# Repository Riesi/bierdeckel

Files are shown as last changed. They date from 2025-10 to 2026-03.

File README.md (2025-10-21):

# Introduction
This is the implementation of an open hardware smart beer coaster.
As a core principle the beer coaster is simply a battery powered scale with LEDs and BLE.
These components enable a variety of interesting applications that can be implemented on top of the provided hardware.
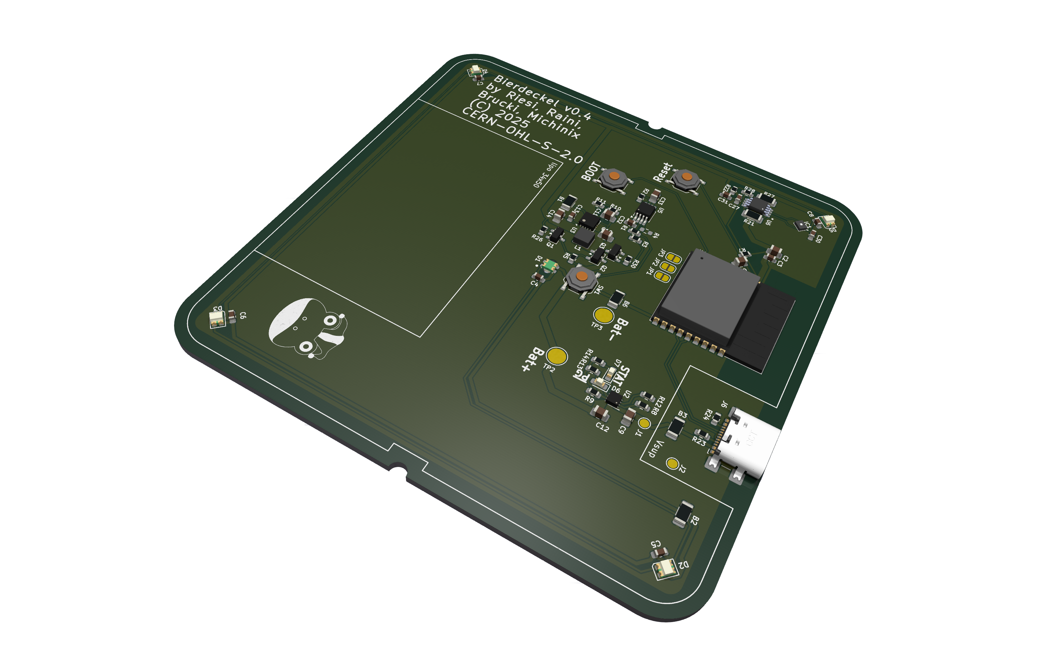
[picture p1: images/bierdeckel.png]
Beerc coaster PCB


## Default app
Currently the default app implementation is a hardcoded rainbow pattern, which gets dimmed relative to the analog input value of the force sensor's measurement. Due to part to part variance on the assembled PCBs the analog values can be different, which means the internal thresholds have to be adapted between PCBs.

## Electro-Mechanical Core Principle
The core component to allow for weight measurements is the piezo-electric force sensor. This sensor translates the force transferred from the coaster's feet into an electric signal, which can be used by the ESP32-C3 microcontroller.

# Code
The code is written in Rust and built with the Rust toolchain provided by Espressif. **It is highly recommended to use Linux for building the code**. The Windows version of the tools needed have some issues, which will make it a lot harder or almost impossible to build the project.

## Setup
There are a few things to install to properly build and flash the firmware onto the device. 
First and foremost the general Rust tooling has to be installed. This means installing `rustup` and making sure `cargo` is working.

### Quickstart on Arch
On Arch you can simply install `rustup`, `espup` and `espflash` via the package manager. You still need to run the toolchain downloads/installs, but you dont have to build anything.
```
sudo pacman -S base-devel rustup espup espflash
rustup default stable
espup install
```
### ESP Toolchain
For the ESP toolchain one has to follow the installation and quickstart guide on the `espup` repository.

https://github.com/esp-rs/espup?tab=readme-ov-file#installation

### Flash Tool
To flash the built firmware the `espflash` tool is needed:

https://github.com/esp-rs/espflash/blob/main/cargo-espflash/README.md#installation

## Building
If everything got properly installed and configured in the previous steps, to build the code one has to simply call:

```
cargo build
```

## Flashing
To build and flash the firmware onto the microcontroller the following command is needed:

```
cargo espflash flash -B 115200 --partition-table partitions.csv --erase-parts ota_1
```

### OTA
The reference beer coaster code implements an OTA update scheme with A/B partitioning.
To generate a OTA-image you simply have to run:

```
espflash save-image --chip esp32c3 target/riscv32imc-esp-espidf/debug/beercoaster beercoaster.bin
```

After this you have to copy the `beercoaster.bin` file into the `bt_flasher` folder and run the flasher with:
```
cargo run
```

## Serial
To connect to the serial interface of the beer coaster this command can be used:
```
espflash  monitor -p /dev/ttyUSB0 -B 115200
```

# PCB Design
The PCB is designed with KiCad. The project should contain all the components to work with it.
When ordering the current version a 1.6mm thick single layer PCB is required, due to assumptions from the mechanical base plate.

# Mechanical
This part of the project is done in FreeCAD and consists of 2 parts which act as the housing for the PCB. The mechanical parts are designed to be 3d printable. The base clips onto the PCB and holds itself in place. 
The key feature of the mechanical design are thin membrane sections, which allow these sections of the base plate to elastically deform. This enables the actuation of buttons on the PCB and the pressure sensor for the weight measurement.

## Material
The design has been tested with PET and ASA, but you can use anything that is:
* water resistant
* doesn't degrade under cyclical deformation
* allows for enough flex to actuate buttons and the pressure sensor

## Assembly Water Tightness
* It is recommended to use silicone to seal the sides of the assembly from water ingress.
* The center LED has to be covered with clear resin to prevent water from getting in.

## BoM
| Part | Amount |
| ---  | --- |
| Base | 1 |
| Foot | 4 |

# Calculations
Contains some files with related calculations for the PCB design. 

# Licensing
The different parts of the beer coaster require different licenses, due to the licenses only covering for example either code or hardware. For this reason the repository contains different licenses. Each subfolder contains the appropriate license for all files and subfolders within.
The current licenses used are:
* GPL-3.0
* CERN-OHL-S-2.0
* Beerware

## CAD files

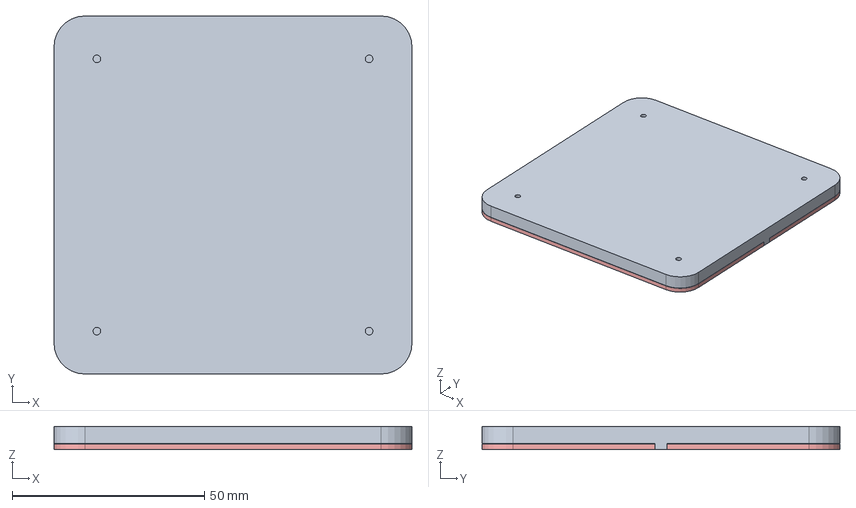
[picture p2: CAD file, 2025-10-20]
mechanical/bierdeckel_base.FCStd
93.0 x 93.0 x 6.10 mm
LED_RGB_1210
C_0805_2012Metric
SOT-23-3
SW_SPST_TL3342
C_0603_1608Metric
R_0603_1608Metric
C_0603_1608Metric020
R_0603_1608Metric034
R_0603_1608Metric035
LED_0603_1608Metric
SW_SPST_TL3348
R_1206_3216Metric
LED_RGB_1220
LED_RGB_1221
ESP32-C3-WROOM-02
C_0805_2012Metric016
R_0603_1608Metric036
R_0603_1608Metric037
C_0805_2012Metric017
C_0603_1608Metric021
USB4110-GF-A001
USB4110-GF-A002
C_0805_2012Metric018
SW_SPST_TL3349
C_0805_2012Metric019
C_0603_1608Metric022
R_0603_1608Metric038
R_1206_3216Metric012
R_0603_1608Metric039
R_0603_1608Metric040
C_0805_2012Metric020
R_0603_1608Metric041
C_0603_1608Metric023
R_0603_1608Metric042
WSON-8-1EP_2x2mm_P0.5mm_EP0.9x1.6mm
C_0603_1608Metric024
R_0603_1608Metric043
R_1206_3216Metric013
R_1206_3216Metric014
SOT-23
R_0603_1608Metric044
LED_RGB_1222
Force_sensor_Knob_ÃÂÃÂ³400um_without mark001
Force_sensor_Knob_ÃÂÃÂ³400um_without mark002
SOT-024
R_0603_1608Metric045
C_0805_2012Metric021
C_0603_1608Metric025
R_0603_1608Metric046
C_0603_1608Metric026
R_0603_1608Metric047
R_0603_1608Metric048
R_0603_1608Metric049
C_0603_1608Metric027
R_1206_3216Metric015
R_0603_1608Metric050
R_1206_3216Metric016
LED_0603_1608Metric004
VSSOP-8_3x3mm_P0.65mm
LED_RGB_1223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

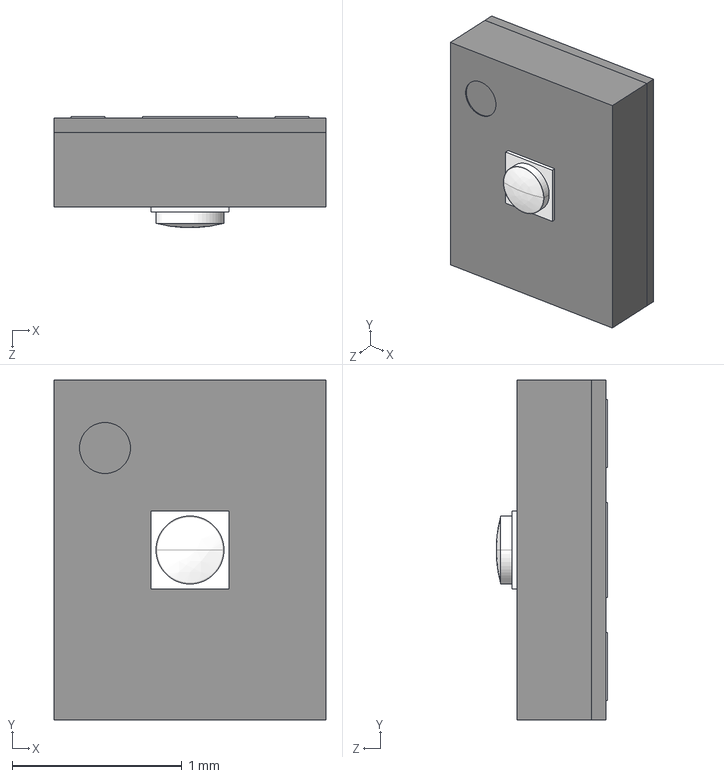
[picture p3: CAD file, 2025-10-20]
pcb_design/3d_models/HSFPAR004A.stp
1.60 x 2.00 x 0.654 mm

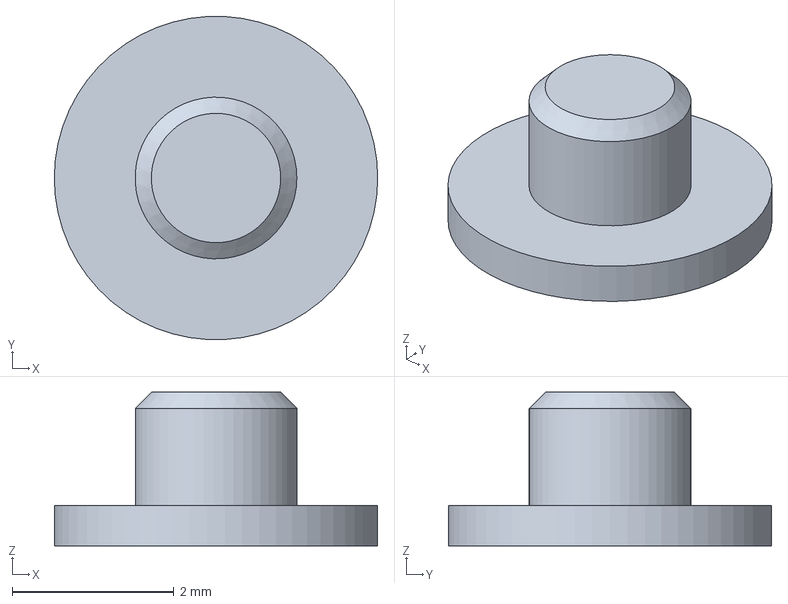
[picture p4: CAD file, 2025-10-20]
mechanical/bierdeckel_foot.FCStd
4.00 x 3.99 x 1.90 mm

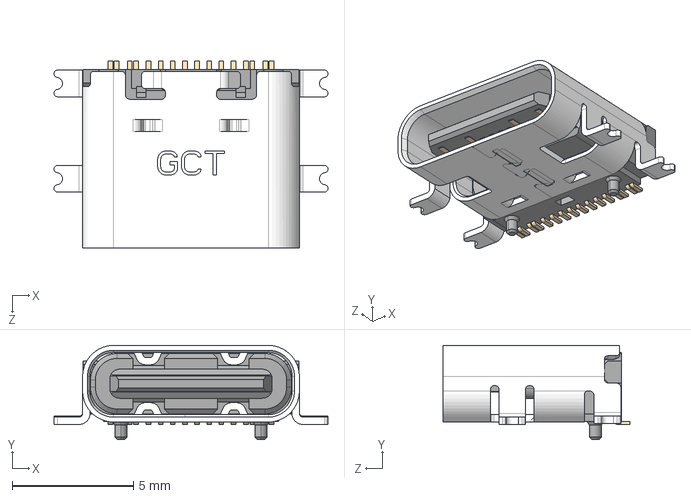
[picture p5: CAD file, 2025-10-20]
pcb_design/3d_models/USB4110-GF-A.stp
11.3 x 3.89 x 7.70 mm

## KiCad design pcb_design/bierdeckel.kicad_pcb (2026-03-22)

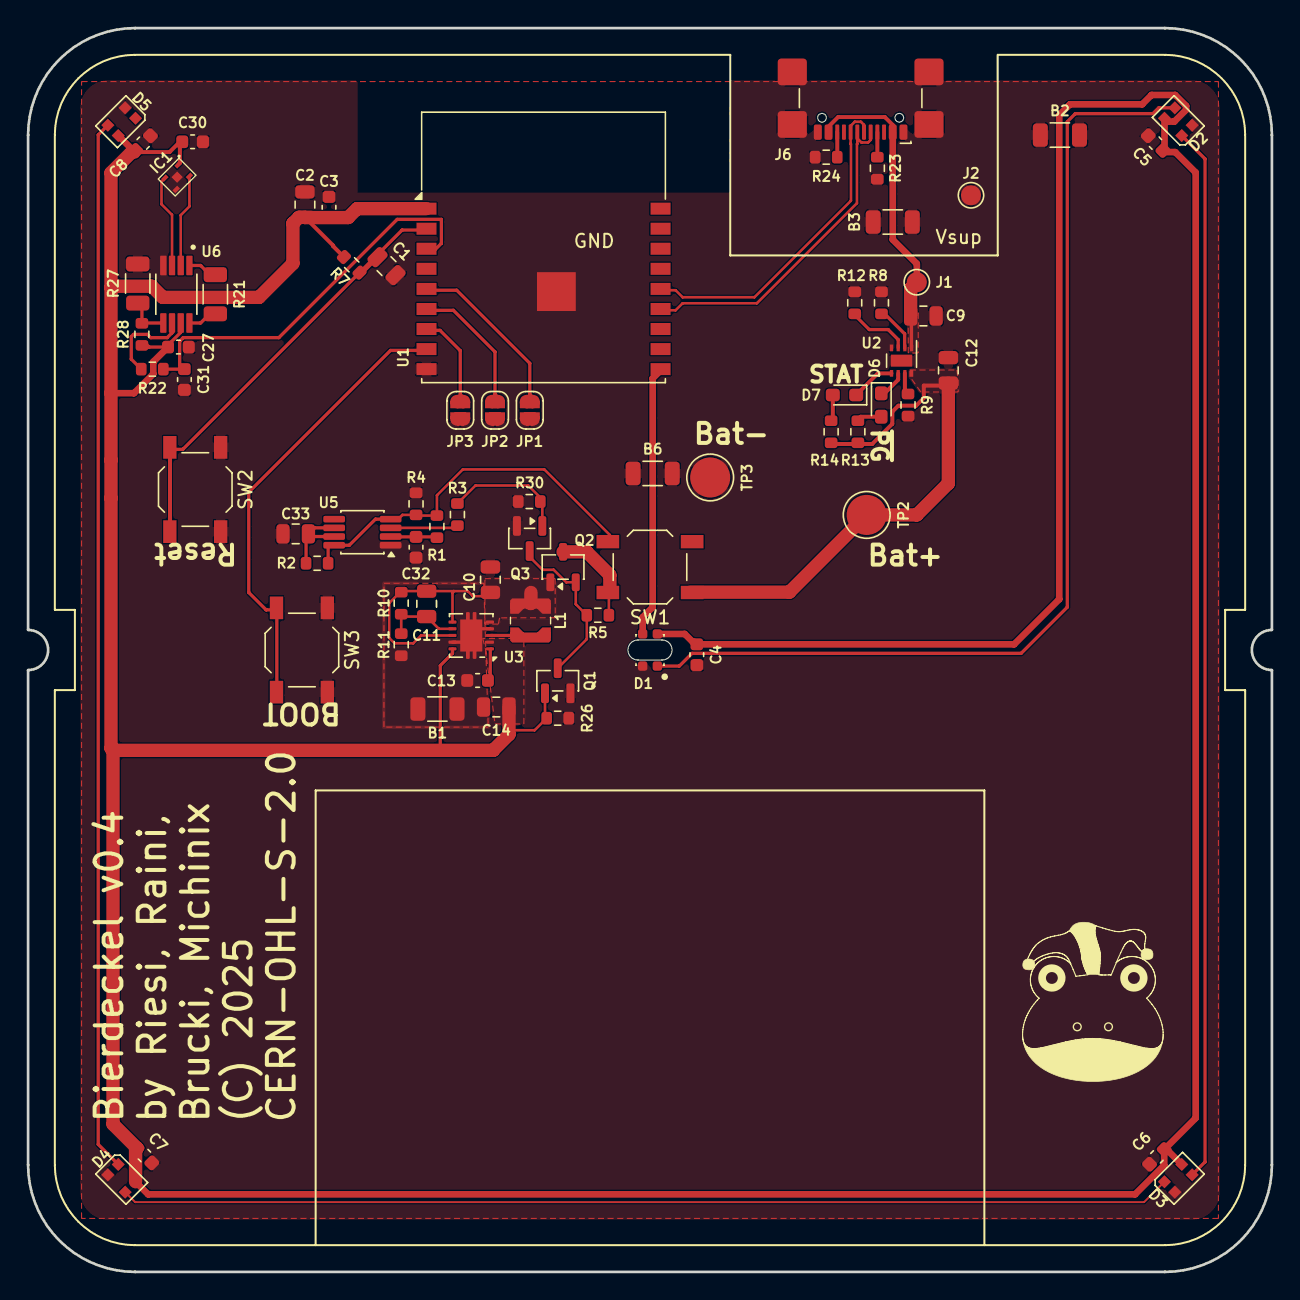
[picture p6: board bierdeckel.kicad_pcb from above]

Board: 2 copper layers, 93.0 x 93.0 mm, 72 parts (0 on the bottom side), 42 nets.

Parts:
B1, B2, B3, B6: 0R; R_1206_3216Metric
C1, C9, C11, C12: 1uF; C_0805_2012Metric
C2, C10, C14, C33: 10uF; C_0805_2012Metric
C3, C4, C5, C6, C7, C8, C13, C27, C30, C31, C32: 0.1uF; C_0603_1608Metric
D1: WS2812B 2020; ws2812B_2020_flipped
D2, D3, D4, D5: WS2812B-2020; LED_WS2812B-2020_PLCC4_2.0x2.0mm
D6: XL-1608UBC-04; LED_0603_1608Metric_Pad1.05x0.95mm_HandSolder
D7: A-SP192DGHC-C01-4T; LED_0603_1608Metric_Pad1.05x0.95mm_HandSolder
IC1: HSFPAR004A
J1, J2: Pogo; TestPoint_Pad_D1.5mm
J6: USB-TYPE-C-020; USB_C_Receptacle_GCT_USB4110
JP1: A0; SolderJumper-2_P1.3mm_Open_RoundedPad1.0x1.5mm
JP2: A1; SolderJumper-2_P1.3mm_Open_RoundedPad1.0x1.5mm
JP3: A2; SolderJumper-2_P1.3mm_Open_RoundedPad1.0x1.5mm
L1: 2.2µH LPS3015-222MRC; LPS3015-222MRC
Q1, Q3: BSS123; SOT-23
Q2: SP20P18T1; SOT-23-3
R1, R3, R8: 620; R_0603_1608Metric
R2, R5, R11, R30: 200k; R_0603_1608Metric
R4, R7, R12, R13, R14, R28: 10k; R_0603_1608Metric
R9: 27k4; R_0603_1608Metric
R10, R26: 2.2M; R_0603_1608Metric
R21: 4k02; R_1206_3216Metric
R22, R23, R24: 5k1; R_0603_1608Metric
R27: 3k; R_1206_3216Metric
SW1, SW2, SW3: PTS526 SK15 SMTR2 LFS; SW_SPST_TL3342
TP2, TP3: TestPoint; TestPoint_Pad_D3.0mm
U1: ESP32-C3-WROOM-02
U2: BQ25176J; WSON-8-1EP_2x2mm_P0.5mm_EP0.9x1.6mm_ThermalVias
U3: TPS61201DRC; Texas_S-PVSON-N10_ThermalVias
U5: LMC555xMM; VSSOP-8_3x3mm_P0.65mm
U6: INA317IDGKR; INA317IDGKR_SOP65P490X110-8N

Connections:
+3.3V: C2.1, C3.1, C4.1, C5.1, C6.1, C7.1, C8.1, C14.1, C27.1, C30.1, D1.4 (VDD), D2.4 (VDD), D3.4 (VDD), D4.4 (VDD), D5.4 (VDD), IC1.1 (VDD), Q1.1 (G), R7.1, R26.1, R28.2, U1.1 (3V3), U3.2 (VOUT), U3.10 (FB), U6.7 (V+)
+BATT: C10.1, C11.1, L1.1, Q2.1 (D), R10.1, U3.5 (VIN), U3.6 (EN), U3.8 (PS)
+BATT_EXT: C12.1, Q2.3 (S), R5.1, R13.1, R14.1, SW1.1, TP2.1 (1_1), U2.8 (OUT)
/AD0: JP1.1 (A), U1.5 (IO6)
/AD1: JP2.1 (A), U1.6 (IO7)
/AD2: JP3.1 (A), U1.7 (IO8)
/LED_DATA: D1.3 (DIN), U1.10 (IO10)
/NE_TOGGLE_OUT: Q3.1 (G), R3.1, R30.1
/Pressure Gauge/VR+: IC1.4 (V1), U6.3 (VIN+)
/Pressure Gauge/VR-: IC1.2 (V2), U6.2 (VIN-)
/Pressure Gauge/Vref: R27.1, R28.1, U6.5 (REF)
/RST: C1.1, R7.2, SW2.2, U1.2 (EN)
/USB+: J6.A6 (D+), J6.B6 (D+), U1.14 (IO19)
/USB-: J6.A7 (D-), J6.B7 (D-), U1.13 (IO18)
/Vcharge: C9.1, J1.1 (1_1), J6.A4 (VBUS), J6.A9 (VBUS), J6.B4 (VBUS), J6.B9 (VBUS), U2.1 (IN)
/Vpress: C31.1, R22.1, U1.3 (IO4)
/~BOOTLOADER: SW3.2, U1.8 (IO9)
GND: B1.1 (A), B1.2 (B), B2.1 (A), B2.2 (B), B3.1 (A), B3.2 (B), B6.1 (A), B6.2 (B), C1.2, C2.2, C3.2, C4.2, C5.2, C6.2, C7.2, C8.2, C9.2, C10.2, C12.2, C13.2, C14.2, C27.2, C30.2, C31.2, C32.2, C33.2, D1.2 (VSS), D2.2 (VSS), D3.2 (VSS), D4.2 (VSS), D5.2 (VSS), IC1.3 (GND_1), IC1.5 (GND_2), J2.1 (1_1), J6.A1 (GND), J6.A12 (GND), J6.B1 (GND), J6.B12 (GND), J6.SH (SHIELD), JP1.2 (B), JP2.2 (B), JP3.2 (B), Q1.2 (S), Q3.2 (S), R4.1, R8.2, R9.2, R11.2, R12.1, R23.2, R24.2, R26.2, R27.2, R30.2, SW2.1, SW3.1, TP3.1 (1_1), U1.9 (GND), U1.19 (GND), U2.4 (GND), U3.4 (PGND), U3.9 (GND), U3.11 (PAD), U5.1 (GND), U6.4 (V_)
unnamed: D1.1 (DOUT), D2.3 (DIN)
unnamed: D2.1 (DOUT), D3.3 (DIN)
unnamed: D3.1 (DOUT), D4.3 (DIN)
unnamed: D4.1 (DOUT), D5.3 (DIN)
unnamed: D6.2 (A), R13.2
unnamed: D6.1 (K), U2.6 (~PG)
unnamed: D7.2 (A), R14.2
unnamed: D7.1 (K), U2.5 (STAT)
unnamed: J6.A5 (CC1), R23.1
unnamed: J6.B5 (CC2), R24.1
unnamed: Q1.3 (D), Q2.2 (G), Q3.3 (D), R5.2
unnamed: R8.1, U2.2 (ISET)
unnamed: R12.2, U2.3 (TS)
unnamed: R9.1, U2.7 (VSET)
unnamed: L1.2, U3.3 (L)
unnamed: C11.2, R10.2, R11.1, U3.7 (UVLO)
unnamed: C13.1, U3.1 (VAUX)
unnamed: C33.1, R2.1, U5.6 (THRES), U5.7 (DISCH)
unnamed: R3.2, U5.3 (OUT)
unnamed: C32.1, R1.1, U5.2 (TRIG)
unnamed: R1.2, R2.2, R4.2, SW1.2, U5.4 (~RST), U5.8 (VCC)
unnamed: R21.2, U6.1 (RG)
unnamed: R21.1, U6.8 (RG__1)
unnamed: R22.2, U6.6 (VOUT)

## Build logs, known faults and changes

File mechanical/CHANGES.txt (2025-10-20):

If you are not shipping the design with a proper git tree, you have to document your changes in this file according to CERN-OHL-S v2.
- initial design drop

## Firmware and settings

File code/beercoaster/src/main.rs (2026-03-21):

#![feature(array_repeat)]
use log::LevelFilter;
use std::array;
use std::collections::{HashMap, VecDeque};
use std::sync::{Arc, Mutex};
use std::thread;
use std::time::Duration;

use esp_idf_hal::adc::attenuation::DB_11;
use esp_idf_hal::adc::oneshot::config::{AdcChannelConfig, Calibration};
use esp_idf_hal::adc::oneshot::*;
use esp_idf_hal::adc::Resolution::Resolution12Bit;
use esp_idf_hal::peripherals::Peripherals;

use ws2812_esp32_rmt_driver::Ws2812Esp32Rmt;

use esp32_nimble::enums::{PowerLevel, PowerType};
use esp32_nimble::utilities::BleUuid;
use esp32_nimble::{uuid128, BLEAdvertisementData, BLEDevice, NimbleProperties};

use num_derive::FromPrimitive;
use num_derive::ToPrimitive;
use num_traits::FromPrimitive;
use num_traits::ToPrimitive;

use esp_ota;

pub mod led_animation;
use crate::led_animation::{LedAnimation, LedPattern};

const WEIGHT_EMPTY: u16 = 380;
const WEIGHT_FULL: u16 = 720;
const WEIGHT_TARGET1: u16 = 500;
const LIGHT_LIMIT: f32 = 0.35;

const MTU_UUID: BleUuid     = uuid128!("BBBBBBBB-21C0-46A4-B722-270E3AE3D830");
const NOTIFY_UUID: BleUuid  = uuid128!("BBD671AA-21C0-46A4-B722-270E3AE3D830");
const CONTROL_UUID: BleUuid = uuid128!("7AD671AA-21C0-46A4-B722-270E3AE3D830");
const WRITE_UUID: BleUuid   = uuid128!("23408888-1F40-4CD8-9B89-CA8D45F8A5B0");
const COM_UUID: BleUuid     = uuid128!("23408877-1F40-4FD8-9B89-CA9D45F8B5B0");

const BIER_SERVICE_UUID: BleUuid = uuid128!("fafafafa-fafa-fafa-fafa-fafafafafafa");


#[derive(Debug, PartialEq, FromPrimitive)]
enum COMState {
    Version = 0x00,
    ADCValue = 0x01,
}

#[derive(Debug, PartialEq, Eq, Hash)]
enum LedState {
    BtWait,
    BtFlashing,
    BtVerified,
    DefaultPattern,
    ActivePattern,
    ErrorPattern,
}

#[derive(ToPrimitive)]
enum OTAControlResponse {
    FlashAck = 0x00,
    FlashNak = 0x01,
    DoneAck = 0x02,
    DoneNak = 0x03,
}

#[derive(FromPrimitive)]
enum OTAControl {
    NOP = 0x00,
    REQUEST = 0x01,
    DONE = 0x02,
    VERIFY = 0x03,
    FLASH = 0x04,
    ABORT = 0x05,
}

struct OTAStateHandle {
    state: OTAState,
}
// from
// https://play.rust-lang.org/?version=stable&mode=debug&edition=2015&gist=ee3e4df093c136ced7b394dc7ffb78e1
#[derive(Debug, PartialEq)]
enum OTAState {
    Initial,
    WaitFlash,
    Failure,
}

#[derive(Debug, Clone)]
enum OTAEvent {
    FlashData,
    DoneFlash,
    Nop,
    Verify,
    Abort,
}

impl OTAStateHandle {
    fn next(&mut self, event: OTAEvent) -> &OTAState {
        match (&self.state, event) {
            (OTAState::Initial, OTAEvent::Abort) => self.state = OTAState::Initial,
            (OTAState::Initial, OTAEvent::Verify) => self.state = OTAState::Initial,
            (OTAState::Initial, OTAEvent::FlashData) => self.state = OTAState::WaitFlash,
            (OTAState::WaitFlash, OTAEvent::DoneFlash) => self.state = OTAState::Initial,
            (OTAState::WaitFlash, OTAEvent::Abort) => self.state = OTAState::Initial,
            (OTAState::WaitFlash, OTAEvent::Nop) => self.state = OTAState::WaitFlash,
            (_s, _e) => self.state = OTAState::Failure,
        }
        &self.state
    }
}

fn main() {
    // It is necessary to call this function once. Otherwise some patches to the runtime
    // implemented by esp-idf-sys might not link properly. See https://github.com/esp-rs/esp-idf-template/issues/71
    esp_idf_svc::sys::link_patches();
    // Bind the log crate to the ESP Logging facilities
    esp_idf_svc::log::EspLogger::initialize_default();

    let peripherals = Peripherals::take().unwrap();
    if let Err(e) = esp_idf_svc::log::set_target_level("NimBLE", LevelFilter::Error) {
        println!("Failed to set log level: {:#?}", e);
    }


    if let Some(timestamp) = option_env!("VERGEN_BUILD_TIMESTAMP") {
        println!("Build Timestamp: {timestamp}");
    }
    let git_desc = if let Some(describe) = option_env!("VERGEN_GIT_DESCRIBE") {
        println!("git describe: {describe}");
        describe
    } else {
        "NAK"
    }.as_bytes();

    let ota_state = Arc::new(Mutex::new(OTAStateHandle {
        state: OTAState::Initial,
    }));

    let mut animation_queue = VecDeque::new();
    animation_queue.push_back(LedState::ActivePattern);
    let animation_queue = Arc::new(Mutex::new(animation_queue));

    let (mut brightness_rx, brightness_tx) = single_value_channel::channel_starting_with(1f32);

    // unsafe{
    //   let mut mac_address = esp_idf_sys::esp_base_mac_addr_get(mac_address);
    // }

    // Finds the next suitable OTA partition and erases it
    let ota = match esp_ota::OtaUpdate::begin() {
        Ok(u) => {
            log::info!("Partition info: {:#?}", u);
            Arc::new(Mutex::new((Some(u), None)))
        }
        Err(e) => {
            log::error!("Failed to find OTA partition: {:#?}", e);
            Arc::new(Mutex::new((None, Some(e.kind()))))
        }
    };

    let ble_device = BLEDevice::take();
    let ble_advertising = ble_device.get_advertising();
    if let Err(e) = ble_device.set_power(PowerType::Default, PowerLevel::P9) {
        log::error!("Failed to set power level: {:#?}", e);
    }

    let server = ble_device.get_server();

    server.on_connect(|server, desc| {
        ::log::info!("Client connected: {:?}", desc.mtu());

        // TODO checkout intervals and power
        server
            .update_conn_params(desc.conn_handle(), 6, 12, 0, 60)
            .unwrap();

        if server.connected_count() < (esp_idf_svc::sys::CONFIG_BT_NIMBLE_MAX_CONNECTIONS as _) {
            ::log::info!("Multi-connect support: start advertising");
            ble_advertising.lock().start().unwrap();
        }
    });

    server.on_disconnect(|_desc, reason| {
        ::log::info!("Client disconnected ({:?})", reason);
    });

    let service = server.create_service(uuid128!("fafafafa-fafa-fafa-fafa-fafafafafafa"));

    // A static characteristic.
    let static_characteristic = service
        .lock()
        .create_characteristic(MTU_UUID, NimbleProperties::READ);
    let _ = ble_device.set_preferred_mtu(
        esp_idf_svc::sys::BLE_ATT_MTU_MAX
            .try_into()
            .unwrap_or(23u16),
    );

    static_characteristic
        .lock()
        .set_value(&ble_device.get_preferred_mtu().to_le_bytes());

    // A characteristic that notifies every second.
    let notifying_characteristic = service.lock().create_characteristic(
        NOTIFY_UUID,
        NimbleProperties::READ | NimbleProperties::NOTIFY,
    );
    notifying_characteristic.lock().set_value(b"nak");

    // A control characteristic.
    let control_characteristic = service.lock().create_characteristic(
        CONTROL_UUID,
        NimbleProperties::READ | NimbleProperties::WRITE,
    );

    let ctrl_animation = animation_queue.clone();
    let ctrl_state = ota_state.clone();
    let notifier = notifying_characteristic.clone();
    let ota_fin = ota.clone();
    control_characteristic
        .lock()
        .on_read(move |_, _| {
            log::debug!("Read from control characteristic.");
        })
        .on_write(move |args| {
            log::debug!(
                "Wrote to control characteristic: {:?} -> {:?}",
                args.current_data(),
                args.recv_data()
            );

            if let Some(control_value) = args.recv_data().first() {
                if let Some(ctrl) = FromPrimitive::from_u8(*control_value) {
                    let event = match ctrl {
                        OTAControl::REQUEST => OTAEvent::Nop,
                        OTAControl::VERIFY => {
                            let val = match ota_fin.lock().unwrap().1.take() {
                                Some(esp_ota::ErrorKind::InvalidRollbackState) => {
                                    ctrl_animation
                                        .lock()
                                        .unwrap()
                                        .push_back(LedState::BtVerified);
                                    esp_ota::mark_app_valid();
                                    log::debug!("Validated image!");
                                    // TODO reenable flashing or maybe reboot
                                    ToPrimitive::to_u8(&OTAControlResponse::DoneAck).unwrap()
                                }
                                Some(e) => {
                                    ctrl_animation
                                        .lock()
                                        .unwrap()
                                        .push_back(LedState::ErrorPattern);
                                    log::error!("{:#?}", e);
                                    ToPrimitive::to_u8(&OTAControlResponse::DoneNak).unwrap()
                                }
                                None => {
                                    log::debug!("Nothing to verify!");
                                    ToPrimitive::to_u8(&OTAControlResponse::DoneNak).unwrap()
                                }
                            };
                            notifier.lock().set_value(&[val]).notify();
                            //esp_ota::rollback_and_reboot().expect("Failed to roll back to working app");
                            OTAEvent::Verify
                        }
                        OTAControl::FLASH => {
                            ctrl_animation
                                .lock()
                                .unwrap()
                                .push_back(LedState::BtFlashing);
                            OTAEvent::FlashData
                        }
                        OTAControl::ABORT => OTAEvent::Abort,
                        OTAControl::DONE => {
                            log::debug!("OTA flashing done!");
                            // Performs validation of the newly written app image and completes the OTA update.
                            let opt = ota_fin.lock().unwrap().0.take();
                            if let Some(ot) = opt {
                                if let Ok(mut completed_ota) = ot.finalize() {
                                    // Sets the newly written to partition as the next partition to boot from.
                                    if let Err(e) = completed_ota.set_as_boot_partition() {
                                        log::error!("{:#?}", e);
                                    } else {
                                        let val = ToPrimitive::to_u8(&OTAControlResponse::DoneAck)
                                            .unwrap();
                                        notifier.lock().set_value(&[val]).notify();
                                        log::debug!("Rebooting!");

                                        thread::sleep(Duration::from_millis(4000));
                                        // Restarts the CPU, booting into the newly written app.
                                        completed_ota.restart();
                                    }
                                } else {
                                    let val =
                                        ToPrimitive::to_u8(&OTAControlResponse::DoneNak).unwrap();
                                    notifier.lock().set_value(&[val]).notify();
                                }
                            };
                            OTAEvent::DoneFlash
                        }
                        _ => OTAEvent::Nop,
                    };
                    let mut a = ctrl_state.lock().unwrap();
                    log::info!("__ Transition from {:?}", a.state);
                    if let OTAState::Failure = a.next(event) {
                        log::error!("Failed state!");
                        ctrl_animation
                            .lock()
                            .unwrap()
                            .push_back(LedState::ErrorPattern);
                        let val = ToPrimitive::to_u8(&OTAControlResponse::FlashNak).unwrap();
                        notifier.lock().set_value(&[val]).notify();
                    } else {
                        let val = ToPrimitive::to_u8(&OTAControlResponse::FlashAck).unwrap();
                        notifier.lock().set_value(&[val]).notify();
                    }
                    log::info!(" to {:?}", a.state);
                } else {
                    log::warn!("Invalid control byte!");
                }
            } else {
                log::warn!("No control byte!");
            }
        });

    // A writable characteristic.
    let writable_characteristic = service
        .lock()
        .create_characteristic(WRITE_UUID, NimbleProperties::READ | NimbleProperties::WRITE);
    let mut chunk_count = 0;
    let wrt_state: Arc<Mutex<OTAStateHandle>> = ota_state.clone();
    let notifier = notifying_characteristic.clone();
    let ota_chunker = ota.clone();
    writable_characteristic
        .lock()
        .on_read(move |_, _| {
            log::info!("Read from writable characteristic.");
        })
        .on_write(move |args| {
            let a = &wrt_state.lock().unwrap();
            match &a.state {
                OTAState::WaitFlash => {
                    let app_chunk = args.recv_data();
                    if let Some(ref mut ot) = ota_chunker.lock().unwrap().0 {
                        if let Err(e) = ot.write(app_chunk) {
                            log::error!("{:#?}", e);
                        }
                    } else {
                        log::error!(
                            "How did we end up here?\nTrying to flash after finishing OTA?"
                        );
                    }
                    if chunk_count % 10 == 0 {
                        let val = ToPrimitive::to_u8(&OTAControlResponse::FlashAck).unwrap();
                        notifier.lock().set_value(&[val]).notify();
                    } else {
                        let val = ToPrimitive::to_u8(&OTAControlResponse::FlashAck).unwrap();
                        notifier.lock().set_value(&[val]).notify();
                    }
                    chunk_count += 1;
                    log::info!("Count: {chunk_count}");
                }
                _ => {
                    log::info!("Nop");
                    let val = ToPrimitive::to_u8(&OTAControlResponse::DoneNak).unwrap();
                    notifier.lock().set_value(&[val]).notify();
                }
            }
        });

    // A com characteristic.
    let com_characteristic = service
        .lock()
        .create_characteristic(COM_UUID, NimbleProperties::READ | NimbleProperties::WRITE);

    let notifier = notifying_characteristic.clone();
    com_characteristic
        .lock()
        .on_read(move |_, _| {
            log::info!("Read from com characteristic.");
        })
        .on_write(move |args| {

            if let Some(com_value) = args.recv_data().first() {
                if let Some(com) = FromPrimitive::from_u8(*com_value) {
                    match com {
                        COMState::Version => {
                            // let data = args.recv_data();
                            let val = git_desc;
                            notifier.lock().set_value(val).notify();
                        }
                        COMState::ADCValue => {
                            // let data = args.recv_data();

                            let val = 1.45f32.to_le_bytes();
                            notifier.lock().set_value(&val).notify();
                        }
                    };                            
                }else{
                    log::info!("Nop");
                    let val = ToPrimitive::to_u8(&OTAControlResponse::DoneNak).unwrap();
                    notifier.lock().set_value(&[val]).notify();
                }
            }
        });

    let ad_res = ble_advertising.lock().set_data(
        BLEAdvertisementData::new()
            .name("Bierdeckel")
            .add_service_uuid(BIER_SERVICE_UUID),
    );
    if let Err(bleerr) = ad_res {
        loop {
            log::error!("Setting server name failed!\n{bleerr}");
            thread::sleep(Duration::from_millis(500));
        }
    }

    let ad_start_res = ble_advertising.lock().start();
    if let Err(bleerr) = ad_start_res {
        loop {
            log::error!("Failed starting ble!\n{bleerr}");
            thread::sleep(Duration::from_millis(500));
        }
    }

    log::info!("Hello, world!");

    let ws2812_pin = peripherals.pins.gpio10;
    let channel = peripherals.rmt.channel0;
    //let mut ws2812 = LedPixelEsp32Rmt::<RGBW8, LedPixelColorGrbw32>::new(channel, ws2812_pin).unwrap();

    let mut ws2812 = Ws2812Esp32Rmt::new(channel, ws2812_pin).unwrap();

    let rainbow = [
        led_animation::RED,
        led_animation::GREEN,
        led_animation::BLUE,
        led_animation::CYAN,
        led_animation::PINK,
    ];
    let rainbow_pat = LedPattern::new(200, rainbow.clone());
    let default_pattern = LedAnimation::new_rotation(4, rainbow_pat);

    let mut bt_wait = LedAnimation::new(2);
    bt_wait.add_pattern(LedPattern::new(800, array::repeat(led_animation::BLUE_H)));
    bt_wait.add_pattern(LedPattern::new(200, array::repeat(led_animation::BLACK)));

    let mut active_pattern = LedAnimation::new(2);
    active_pattern.add_pattern(LedPattern::new(1500, array::repeat(led_animation::GREEN_H)));
    active_pattern.add_pattern(LedPattern::new(400, array::repeat(led_animation::BLACK)));

    let mut bt_flashing = LedAnimation::new(4);
    bt_flashing.add_pattern(LedPattern::new(300, array::repeat(led_animation::YELLOW_H)));
    bt_flashing.add_pattern(LedPattern::new(200, array::repeat(led_animation::BLACK)));
    let mut bt_verified = LedAnimation::new(4);
    bt_verified.add_pattern(LedPattern::new(300, array::repeat(led_animation::PINK_H)));
    bt_verified.add_pattern(LedPattern::new(200, array::repeat(led_animation::BLACK)));
    let mut error_pattern = LedAnimation::new(4);
    error_pattern.add_pattern(LedPattern::new(300, array::repeat(led_animation::RED)));
    error_pattern.add_pattern(LedPattern::new(200, array::repeat(led_animation::BLACK)));

    let mut led_map: HashMap<LedState, LedAnimation> = HashMap::new();
    led_map.insert(LedState::BtWait, bt_wait);
    led_map.insert(LedState::BtFlashing, bt_flashing);
    led_map.insert(LedState::BtVerified, bt_verified);
    led_map.insert(LedState::DefaultPattern, default_pattern);
    led_map.insert(LedState::ActivePattern, active_pattern);
    led_map.insert(LedState::ErrorPattern, error_pattern);

    animation_queue.lock().unwrap().push_back(LedState::BtWait);
    animation_queue
        .lock()
        .unwrap()
        .push_back(LedState::DefaultPattern);

    let _thread_led = thread::spawn(move || {
        let mut state = LedState::DefaultPattern;
        let mut cycle = 0;
        let mut fact = 1f32;
        loop {
            if let Some(st) = animation_queue.lock().unwrap().pop_front() {
                state = st;
                cycle = 0;
            }

            let led_ani = led_map.get_mut(&state).unwrap();
            loop {
                led_ani.next_pattern().map(|p| {
                    fact = *brightness_rx.latest();
                    let mut data = p.led_data.clone();
                    for da in data.iter_mut() {
                        da.r = (da.r as f32 * fact) as u8;
                        da.g = (da.g as f32 * fact) as u8;
                        da.b = (da.b as f32 * fact) as u8;
                    }
                    let d = data.iter().copied();
                    ws2812.write_nocopy(d).unwrap();
                    thread::sleep(Duration::from_millis(p.time_step_ms()));
                });
                if cycle < led_ani.get_min_repeats() {
                    cycle += 1;
                } else {
                    break;
                }
            }
        }
    });

    let adc = AdcDriver::new(peripherals.adc1).unwrap();

    // configuring pin to analog read, you can regulate the adc input voltage range depending on your need
    // for this example we use the attenuation of 11db which sets the input voltage range to around 0-3.6V
    let config = AdcChannelConfig {
        attenuation: esp_idf_hal::adc::attenuation::NONE,
        resolution: Resolution12Bit,
        calibration: Calibration::Curve,
    };

    let mut adc_pin = AdcChannelDriver::new(&adc, peripherals.pins.gpio4, &config).unwrap();
    let mut factor = 1f32;
    loop {
        thread::sleep(Duration::from_millis(100));
        let adc_val = adc.read(&mut adc_pin).unwrap();
        let f = if adc_val > WEIGHT_FULL {
            1f32
        } else {
            if adc_val > WEIGHT_TARGET1 {
                1f32 - (WEIGHT_FULL - adc_val) as f32
                    / ((WEIGHT_FULL - WEIGHT_TARGET1) as f32 / (1f32 - LIGHT_LIMIT))
            } else {
                if adc_val > WEIGHT_EMPTY {
                    LIGHT_LIMIT
                        - (WEIGHT_TARGET1 - adc_val) as f32
                            / ((WEIGHT_TARGET1 - WEIGHT_EMPTY) as f32 / LIGHT_LIMIT)
                } else {
                    0f32
                }
            }
        };
        if factor != f {
            factor = f;
            brightness_tx.update(factor).unwrap();
        }
        log::info!("ADC value: {}mV, scale {}", adc_val, factor);
    }
}

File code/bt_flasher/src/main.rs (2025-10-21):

use btleplug::api::{Central, CentralEvent, Manager as _, Peripheral, ScanFilter, WriteType};
use btleplug::platform::{Adapter, Manager};
use std::error::Error;
use tokio::time;
use uuid::{uuid, Uuid};
use futures::stream::StreamExt;
use std::time::{Duration, SystemTime, UNIX_EPOCH};

use num_derive::FromPrimitive;    
use num_traits::FromPrimitive;
use num_derive::ToPrimitive;    
use num_traits::ToPrimitive;

#[derive(FromPrimitive,Debug)]
enum OTAControlResponse {
  FLASH_ACK = 0x00,
  FLASH_NAK = 0x01,
  DONE_ACK = 0x02,
  DONE_NAK = 0x03,
}

#[derive(ToPrimitive)]
enum OTAControl{
  NOP = 0x00,
  REQUEST = 0x01,
  DONE = 0x02,
  VERIFY = 0x03,
  FLASH = 0x04,
  ABORT = 0x05,
}


const PERIPHERAL_NAME_MATCH_FILTER: &str = "Bierdeckel";

const MTU_UUID: Uuid     = uuid!("BBBBBBBB-21C0-46A4-B722-270E3AE3D830");
const NOTIFY_UUID: Uuid  = uuid!("BBD671AA-21C0-46A4-B722-270E3AE3D830");
const CONTROL_UUID: Uuid = uuid!("7AD671AA-21C0-46A4-B722-270E3AE3D830");
const WRITE_UUID: Uuid   = uuid!("23408888-1F40-4CD8-9B89-CA8D45F8A5B0");

const BIER_SERVICE_UUID: Uuid  = uuid!("fafafafa-fafa-fafa-fafa-fafafafafafa");

#[tokio::main]
async fn main() -> Result<(), Box<dyn Error>> {
    let manager = Manager::new().await?;
    let adapter_list = manager.adapters().await?;
    if adapter_list.is_empty() {
        eprintln!("No Bluetooth adapters found");
    }
    // Flash
    scan(&adapter_list, false).await.unwrap();

    // Delay to prevent 
    time::sleep(Duration::from_millis(4000)).await;

    // Verify
    scan(&adapter_list, true).await.unwrap();

    Ok(())
}
async fn scan(adapter_list: &Vec<Adapter>, verify: bool) -> Result<(), ()> {
    for adapter in adapter_list.iter() {
        println!("Starting scan...");

        if let Err(e) = adapter.stop_scan().await{
            println!("{:?}",e );
        }

        let mut event_stream = adapter.events().await.unwrap();
        let filter = ScanFilter{services: vec![BIER_SERVICE_UUID]};
        adapter
            .start_scan(filter)
            .await
            .expect("Can't scan BLE adapter for connected devices...");

        while let Some(event) = event_stream.next().await {
            match event {
                CentralEvent::DeviceDiscovered(id) => {
                    let peripheral = adapter.peripheral(&id).await.unwrap();
                    let properties = peripheral.properties().await.unwrap();
                    let name = properties
                        .and_then(|p| p.local_name)
                        .unwrap_or_default();
                    if name.eq(PERIPHERAL_NAME_MATCH_FILTER) {
                        println!("Connecting to Bierdeckel: {:?}", id);
                        let is_connected = peripheral.is_connected().await.unwrap();
                        if !is_connected {
                            // Connect if we aren't already connected.
                            if let Err(err) = peripheral.connect().await {
                                eprintln!("Error connecting to peripheral, skipping: {}", err);
                            }
                        }
                    }else{
                        println!("Ignoring Device: {:?}, Name: {}", id, name);
                    }
                }
                CentralEvent::StateUpdate(state) => {
                    println!("AdapterStatusUpdate {:?}", state);
                }
                CentralEvent::DeviceConnected(id) => {
                    println!("DeviceConnected: {:?}", id);
                    let peripheral = adapter.peripheral(&id).await.unwrap();
                    let is_connected = peripheral.is_connected().await.unwrap();
                    let properties = peripheral.properties().await.unwrap();
                    let local_name = properties
                        .unwrap()
                        .local_name
                        .unwrap_or(String::from("(peripheral name unknown)"));
                    println!(
                        "Peripheral {:?} is connected: {:?}",
                        &local_name, is_connected
                    );
                    if !is_connected {
                        return Err(());
                    }
                    if verify{
                        println!("Validating image");
                        validate_firmware(peripheral).await.unwrap();
                    }else{
                        println!("Flashing image");
                        flash_firmware(peripheral).await.unwrap();
                    }

                    if let Err(e) = adapter.stop_scan().await{
                        println!("{:?}",e );
                    }
                    break;
                }
                CentralEvent::DeviceDisconnected(id) => {
                    println!("DeviceDisconnected: {:?}", id);
                }
                CentralEvent::ManufacturerDataAdvertisement {
                    id,
                    manufacturer_data,
                } => {
                    println!(
                        "ManufacturerDataAdvertisement: {:?}, {:?}",
                        id, manufacturer_data
                    );
                }
                CentralEvent::ServiceDataAdvertisement { id, service_data } => {
                    println!("ServiceDataAdvertisement: {:?}, {:?}", id, service_data);
                }
                CentralEvent::ServicesAdvertisement { id, services } => {
                    let services: Vec<String> =
                        services.into_iter().map(|s| s.to_string()).collect();
                    println!("ServicesAdvertisement: {:?}, {:?}", id, services);
                }
                _ => {}
            }
        }
    }
    Ok(())
}
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

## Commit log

2023-10-13 initial design and code drop
    [bierdeckel.kicad_pcb, bierdeckel.kicad_sch, energy.ods]
2024-03-10 Implement Simon's layout suggestions
    [bierdeckel.kicad_pcb, bierdeckel.kicad_sch, bom.csv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]
2024-05-01 remove ATTiny; fix LED footprints; start cleanup
    [bierdeckel.kicad_pcb, bierdeckel.kicad_sch, leds.kicad_sch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]
2024-05-03 improve layout further
    [bierdeckel.kicad_pcb, bierdeckel.kicad_sch, leds.kicad_sch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]
2024-05-22 fix battery charging IC circuit missing TS pulldown
    [power.kicad_sch]
2024-05-26 fix some layout issues
    [bierdeckel.kicad_pcb, bierdeckel.kicad_sch, leds.kicad_sch]
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2024-05-27 correct buck/boost bootstrap circuit to handle falling/rising hysteresis on Uvlo
    [bierdeckel.kicad_pcb, power.kicad_sch]
2024-05-27 give PCB a title
    [bierdeckel.kicad_pcb]
2024-05-29 improve buck/boost footprint based on datasheet
    [bierdeckel.kicad_pcb]
2024-05-29 improve edge marker, get rid of 1 power bridge
    [bierdeckel.kicad_pcb, bierdeckel.kicad_sch]
2024-05-29 update version number
    [bierdeckel.kicad_pcb]
2024-05-29 improve solder paste masking
    [bierdeckel.kicad_pcb]
2024-05-30 improve routing
    [bierdeckel.kicad_pcb]
2024-05-30 change pressure bridge to four DMS
    [bierdeckel.kicad_pcb, leds.kicad_sch, pressure.kicad_sch]
2024-06-02 add nudge into edge cut; improve routing and wheat stone bridge position
    [bierdeckel.kicad_pcb]
2024-06-02 add an example lipo as user comment
    [bierdeckel.kicad_pcb]
2024-06-06 change to 2 pressure gauge strips
    [bierdeckel.kicad_pcb, bierdeckel.kicad_sch, power.kicad_sch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]
2024-06-06 remove other PCB shapes
    [bierdeckel_frosch.kicad_pcb, bierdeckel_frosch.kicad_sch, bierdeckel_rund.kicad_pcb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]
2024-07-25 update design; add 3d models to everything; add notches to PCB
    [bierdeckel.kicad_pcb, bierdeckel.kicad_sch, pressure.kicad_sch]
2024-07-25 reannotate components and move some designators
    [bierdeckel.kicad_pcb, bierdeckel.kicad_sch, leds.kicad_sch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]
2024-11-17 code drop BT firmware with LED example
    [partitions.csv]
2024-11-17 update design
    [bierdeckel.kicad_pcb, pressure.kicad_sch]
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2024-12-28 fix output unit in bt flasher
    [main.rs]
2024-12-28 fix watchdog timeout error due to empty main loop
    [main.rs]
2024-12-28 add error pattern to failure transition
    [main.rs]
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2025-01-19 fix brightness initial value
    [main.rs]
2025-01-20 fix less than empty weight to zero and clean up code
    [main.rs]
2025-02-01 bump dependencies and fix compilation
    [main.rs]
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2025-02-13 fix ERC and DRC
    [bierdeckel.kicad_pcb, bierdeckel.kicad_sch, leds.kicad_sch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]
2025-02-13 fix ERC
    [bierdeckel.kicad_pcb]
2025-03-18 update to kicad 9.0 and place Qi-charge IC
    [bierdeckel.kicad_pcb, bierdeckel.kicad_sch, leds.kicad_sch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]
2025-03-20 continue Qi-Charge circuit
    [power.kicad_sch]
2025-03-31 implement initial power latching idea
    [bierdeckel.kicad_pcb, bierdeckel.kicad_sch, leds.kicad_sch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]
2025-04-01 update pcb file and fix a few silkscreen overlaps
    [bierdeckel.kicad_pcb]
2025-04-02 continue Qi-Charger work
    [bierdeckel.kicad_pcb, power.kicad_sch]
2025-06-13 start reshuffeling for qi-charge version
    [bierdeckel.kicad_pcb, bierdeckel.kicad_sch, power.kicad_sch]
2025-07-14 before gauge replacement
    [bierdeckel.kicad_pcb, pressure.kicad_sch]
2025-07-14 initial piezo resistive IC impl
    [bierdeckel.kicad_pcb, pressure.kicad_sch]
2025-07-15 continue new pressure sensor implementation
    [bierdeckel.kicad_pcb, pressure.kicad_sch]
2025-07-16 continue routing
    [bierdeckel.kicad_pcb, pressure.kicad_sch]
2025-07-17 continue refactor
    [bierdeckel.kicad_pcb, bierdeckel.kicad_sch, leds.kicad_sch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]
2025-07-17 further work
    [bierdeckel.kicad_pcb, bierdeckel.kicad_sch, leds.kicad_sch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]
2025-07-24 before USB connector
    [bierdeckel.kicad_pcb, bierdeckel.kicad_sch]
2025-07-24 add usb c connector
    [bierdeckel.kicad_pcb, bierdeckel.kicad_sch, power.kicad_sch]
2025-07-24 remove excessive ESP mini
    [bierdeckel.kicad_pcb, bierdeckel.kicad_sch]
2025-07-24 finish up routing and fix latching
    [bierdeckel.kicad_pcb, bierdeckel.kicad_sch, leds.kicad_sch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]
2025-07-29 replace some components for JLC order
    [bierdeckel.kicad_pcb, bierdeckel.kicad_sch, leds.kicad_sch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]
2025-07-29 change some more components to LCSC ones
    [bierdeckel.kicad_sch, power.kicad_sch]
2025-07-30 start implementing mechanical base
    [bierdeckel_base.FCStd]
2025-08-04 update PCB usb position and further base work
    [bierdeckel.kicad_pcb, bierdeckel_base.FCStd]
2025-08-06 implement more parts of the base
    [bierdeckel_base.FCStd]
2025-08-07 further mechanical work
    [bierdeckel_base.FCStd]
2025-08-14 reposition buttons and finish up initial base design
    [bierdeckel.kicad_pcb, bierdeckel_base.FCStd]
2025-08-18 further base work
    [bierdeckel_base.FCStd]
2025-08-18 update base designs
    [bierdeckel_base.FCStd, bierdeckel_foot.FCStd]
2025-09-02 add 555 based power latching
    [bierdeckel.kicad_sch]
2025-09-02 route power latch circuit
    [bierdeckel.kicad_pcb, bierdeckel.kicad_sch]
2025-09-04 prepare for ordering
    [bierdeckel.kicad_pcb, bierdeckel.kicad_sch, power.kicad_sch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]
2025-09-04 add unit to capacitor value
    [bierdeckel.kicad_pcb, bierdeckel.kicad_sch]
2025-09-23 minor adjustments of coaster base
    [bierdeckel_base.FCStd]
2025-09-23 increase lipo holder length
    [bierdeckel_base.FCStd]
2025-09-29 bump some dependency versions; pin compiler version; remove broken embassy-time-driver dep
2025-09-30 fix adc readout logic for piezo pressure sensor
    [main.rs]
2025-10-06 fix: change ADC config to use factory curve
    [main.rs]
2025-10-06 begin improving power latching circuit
    [bierdeckel.kicad_sch, power.kicad_sch]
2025-10-06 disable embassy-timer-driver due to being broken with current toolchains
2025-10-11 change power ON and latching circuit to use FETs
    should reduce leakage currents :)
    [bierdeckel.kicad_pcb, bierdeckel.kicad_sch, power.kicad_sch]
2025-10-11 add info in license to PCB design
    [bierdeckel.kicad_pcb, bierdeckel.kicad_sch, leds.kicad_sch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]
2025-10-11 move PCB files into subfolder
    [bierdeckel.csv, bierdeckel.kicad_pcb, bierdeckel.kicad_sch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]
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2025-10-11 fix filter
2025-10-20 add licensing to components
    [bierdeckel_base.FCStd, bierdeckel_foot.FCStd]
2025-10-20 add license to PCB silkscreen
    [bierdeckel.kicad_pcb]
2025-10-20 add 3d models of some components
    [HSFPAR004A.stp, USB4110-GF-A.stp, bierdeckel.kicad_pcb]
2025-10-20 update PCB in base CAD file
    [bierdeckel_base.FCStd]
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2025-10-21 rename beercoaster main code to make it usage more obvious
    [partitions.csv]
2026-03-21 initial flasher fixes to get example working
    [main.rs]
2026-03-21 initial version print via BT
    fix dirty status and simplify version get in gui
    [main.rs]
2026-03-21 update PCB to Kicad 10
    [bierdeckel.kicad_pcb, bierdeckel.kicad_sch, leds.kicad_sch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]
2026-03-22 vendor more symbols
    [bierdeckel.kicad_pcb, bierdeckel.kicad_sch, pressure.kicad_sch]

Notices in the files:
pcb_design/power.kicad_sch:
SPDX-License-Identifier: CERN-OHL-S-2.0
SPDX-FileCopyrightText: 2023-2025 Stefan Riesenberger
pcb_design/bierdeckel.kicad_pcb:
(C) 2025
